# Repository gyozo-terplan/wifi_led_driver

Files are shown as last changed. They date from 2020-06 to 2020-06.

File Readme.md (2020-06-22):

# ESP8266 BASED WIFI LED DRIVER

ESP8266 based WiFi LED driver is a high capacity led driver, which can be operated via MQTT or with a physical button. It has 3-channels capable of delivering 1A current per channel. 

> **WARNING:**  **!!!  USE THIS DEVICE AT YOUR OWN RISK! I AM NOT AN EXPERT ON ELECTRONICS MALFUNCTIONS CAN HAPPEN WITH THE BOARD (fire hazard etc.) Always unplug it, if you do not use !!!**

# Features

- Controllable via WIFI + MQTT
- 3 channels, 1A current per channel
- Lights are dimmable
- Can be set up in a browser, no need to hard-code WiFi credentials
- Physical switch to turn the LED strips on and off
- MQTT Status feedback
- Openhab compatible
- Wired and OTA firmware update 

# Hardware

## Parts list

- 10K resistor
- ESP12
- LM2596SX-3.3/NOPB
- 560uF capacitor
- Inductor
- 680uF capacitor
- SS34-E3/57T schottky diode
- Header-Male-2.54_1x8
- Terminal Block 
- 100nF capacitor (optional)
- IRLB8743PBF transistor
- DC-005-5A-3.0 socket

Detailed parts list is in the pcb folder BOM file.

## Accessories needed

- Power suppply 12V 5A min. rated supply with 3.0 mm x 5.5 mm plug
- USB-TTL CP2102 (to upload firmware to the device) 
- Dupont cables (5 pieces)
- Momentary switch (optional)
- analog LED strip (3, 1A max)

## Assembly

- Order the PCB (gerber file in the pcb folder)
- Order parts 
- Solder the parts to the PCB. Beware the order of the soldering, if you are using soldering iron

The final device should look like this:
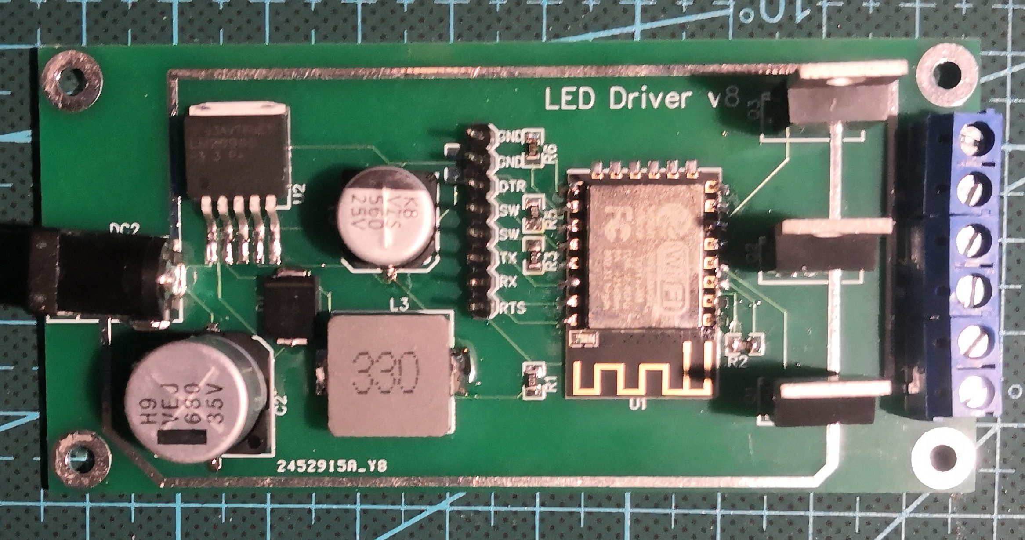
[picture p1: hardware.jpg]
Hardware


# Firmware

## Required software environment 

- Arduino IDE to flash the device before the first usage
- MQTT client to send commands to the unit via WiFi (it can be an app, or software running on a computer)
- MQTT broker on running on the same network as the LED driver  

## Firmware flash

- To upload the firmware you need to install Arduino IDE
- You need to install the ESP board in Arduino IDE (instructions [here](https://randomnerdtutorials.com/how-to-install-esp8266-board-arduino-ide/))
- Install IotWebConf and MQTT library for Arduino by Joel Gaehwiler (guide to install Arduino libraries [here](https://www.arduino.cc/en/guide/libraries))
- Open the firmware in Arduino IDE (located in the firmware folder: wifi_ledstrip.ino)
- Connect the CP2102 USB-TTL device to the computer via USB
- Connect the CP2102 USB-TTL device to the board, wiring diagram:

```
+----------------+               +----------------+
|                |               |                |
|             GND+---------------+GND             |
|                |               |                |
|              RX+---------------+TX  Wifi LED    |
|     CP2102     |               |     Driver     |
|              TX+---------------+RX              |
|                |               |                |
|             DTR+---------------+DTR             |
|                |               |                |
|             RTS+---------------+RTS             |
|                |               |                |
+----------------+               +----------------+
```

- Upload the firmware with Arduino IDE

# Setup

- The device will be in AP mode first when powered on, later it switches to client mode and try to connect to a hotspot 
- Search for a network on a WiFi capable device (smartphone, computer)
- Connect to the device (SSID: led_driver, password: proba1234)
- Go to the http://192.168.4.1  address in a browser
- Go to the configuration page
- You can set:
		- Thing name: device name
		- AP password: the password of the device if it is in AP mode
		- WiFi SSID: name of the WiFi hotspot where the device will connect if it switches to client mode
		- WiFi password: password of the WiFi hotspot where the device will connect if it switches to client mode
		- MQTT server address: address of the MQTT broker
		- MQTT topic name: the mqtt topic which will be used to send messages to the device
		- MQTT name: MQTT name of the device
		- Default light intensity: numeric value which sets the light intensity (between 0 and 100) if the button pressed on the device

## Usage

- Plug in the device, it should automatically connect to the WiFi network and to the MQTT broker
- Connect to the MQTT broker on your device (smartphone, tablet, computer, any device that can run MQTT device)
- Send the requested light intensity value to the ```
/MQTT topic name/MQTT name/action``` topic
- If the message received and the light intensity value is different than the previous you should get a message ```/MQTT topic name/MQTT name/status``` topic which shows you the light intensity which was just set
- If you would like to use the device without giving MQTT commands you can use a physical momentary switch, you can connect the switch to the SW pins

## TODO

- Improve thermal performance
- Create secure MQTT connection capability

## Copyright

See [LICENSE](https://github.com/gyozo-terplan/wifi_led_driver/blob/master/LICENSE) for details.

## Credits

- The firmware heavily based on Balázs Kelemen's [IotWebConf](https://github.com/prampec/IotWebConf) library

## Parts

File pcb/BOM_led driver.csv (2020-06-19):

ID | Name | Designator | Footprint | Quantity | Manufacturer Part | Manufacturer | Supplier | Supplier Part | LCSC Assembly
1 | 10K | R1,R2,R3,R5,R6 | 0805 | 5 | RC0805JR-0710KL | YAGEO | LCSC | C100047
2 | ESP12 | U1 | ESP-12F (ESP8266 MODULE) (BAGUNDA) | 1 | ESP-12F(ESP8266MOD) | Ai-Thinker | LCSC | C82891
3 | LM2596SX-3.3/NOPB | U2 | TO-263-5 | 1 | LM2596SX-3.3/NOPB | TI | LCSC | C7929 | Yes
4 | 560uF | C3 | CAP-T-10*10 | 1 | VZS561M1E1010-TRO | Lelon | LCSC | C249979
5 | Sunltech | L3 | L-SMD-13.45X12.6X6.5 | 1 | SLO1365H330MTT | Sunltech Tech | LCSC | C364090
6 | 680uF | C2 | CAP-T-12.5*13.5 | 1 | VEJ681M1V1313-TRO | Lelon | LCSC | C249685
7 | SS34-E3/57T | D1 | SMC(DO-214AB) | 1 | SS34-E3/57T | VISHAY | LCSC | C13354 | Yes
8 | Header-Male-2.54_1x8 | H2 | 210S-1X8P | 1 | 210S-1*8P L=11.6MMGold-plated black | Ckmtw | LCSC | C124381
9 | Terminal Block 2 | J1,J2,J3 | TERMINAL_BLOCK_2P_5 | 3 | ? |  | ME
10 | 100nF | C1 | 0805 | 1 | 0805F104Z500 | WTC | LCSC | C89574
11 | IRLB8743PBF | Q1,Q2,Q3 | TO-220(TO-220-3) | 3 | IRLB8743PBF | IR | LCSC | C2663
12 | DC-005-5A-3.0 | DC2 | DC-IN_3P-DC-005-5A-3.0 | 1 | DC-005-5A-3.0 | XKB Enterprise | LCSC | C388625

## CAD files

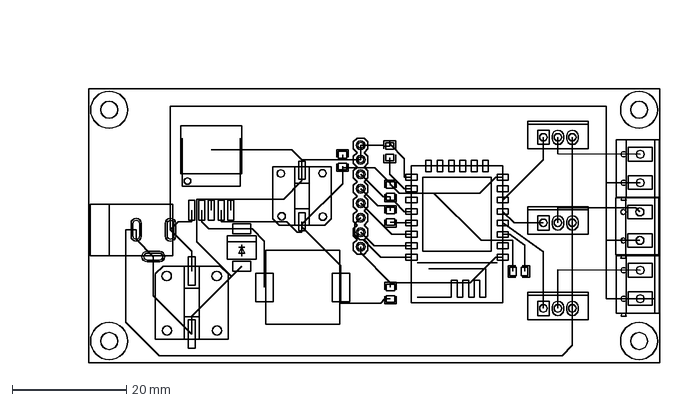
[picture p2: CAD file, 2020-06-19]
pcb/pcb.dxf
112.7 x 60.7 mm

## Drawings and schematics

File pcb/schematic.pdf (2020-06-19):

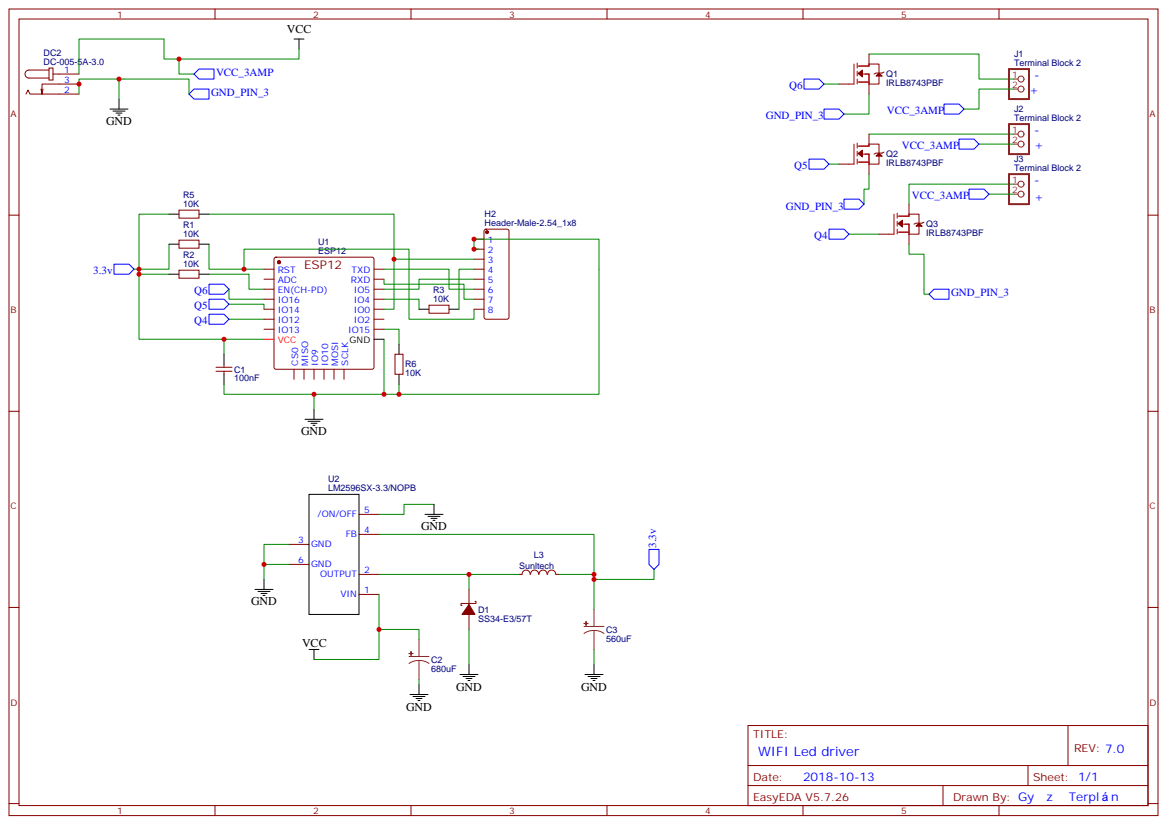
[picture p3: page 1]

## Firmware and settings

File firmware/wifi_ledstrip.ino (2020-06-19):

/// Loading libraries
#include <IotWebConf.h>
#include <MQTT.h>





/// Defining inputs and outputs of the ESP
#define J1_PIN 16   
#define J2_PIN 12 
#define J3_PIN 14  
#define BUTTON_READ 4 
#define BUTTON_SEND 5 


/// Defining GUI variables
#define STRING_LEN 128
#define NUMBER_LEN 32
const char thingName[] = "led_driver";
const char wifiInitialApPassword[] = "proba1234";
char mqttServerAddress[STRING_LEN];
char mqtt_topic[STRING_LEN];
char mqtt_name[STRING_LEN];
char default_intensity_input[STRING_LEN];


/// Defining variables of the button switch 
int intensity = 0;
int prev_intensity = 0;
long my_time = 0;
long debounce = 50; 
int multiplier;
int default_intensity;


/// Defining variables of the MQTT controll 
int state = HIGH;      
int reading;           
int previous = LOW; 



/// Callback method declarations
void wifiConnected();
void configSaved();
boolean formValidator();
void mqttMessageReceived(String &topic, String &payload);



/// Defining used modules
DNSServer dnsServer;
WebServer server(80);
WiFiClient net;
MQTTClient mqttClient;
HTTPUpdateServer httpUpdater;



/// GUI variable configuration
IotWebConf iotWebConf(thingName, &dnsServer, &server, wifiInitialApPassword);
IotWebConfParameter mqttServer_Param = IotWebConfParameter("MQTT server address", "mqttServer", mqttServerAddress, STRING_LEN);
IotWebConfParameter mqttTopic_Param = IotWebConfParameter("MQTT topic name", "mqtt_topic", mqtt_topic, STRING_LEN);
IotWebConfParameter mqttName_Param = IotWebConfParameter("MQTT name", "mqtt_name", mqtt_name, STRING_LEN);
IotWebConfParameter default_intensity_Param = IotWebConfParameter("Default light intensity", "default_intensity", default_intensity_input, NUMBER_LEN, "number", "1..100", NULL, "min='1' max='100' step='1'");


/// Defining variables for automatic reconnection
boolean needMqttConnect = false;
boolean needReset = false;
unsigned long lastMqttConnectionAttempt = 0;


/// Defining MQTT topics
char mqttActionTopic[STRING_LEN];
char mqttStatusTopic[STRING_LEN];





void setup() {
  
  Serial.begin(115200);
  Serial.println("Booting");


  /// Set the extra parameters of the GUI
  iotWebConf.addParameter(&mqttServer_Param);
  iotWebConf.addParameter(&mqttTopic_Param);
  iotWebConf.addParameter(&mqttName_Param);
  iotWebConf.addParameter(&default_intensity_Param);


  /// Set callback functions
  iotWebConf.setConfigSavedCallback(&configSaved);
  iotWebConf.setupUpdateServer(&httpUpdater);
  iotWebConf.setFormValidator(&formValidator);
  iotWebConf.setWifiConnectionCallback(&wifiConnected);


  /// Initialize the configuration
  boolean validConfig = iotWebConf.init();
  if (!validConfig)
  {
    mqttServerAddress[0] = '\0';
  }
  

  /// Set up required URL handlers on the web server
  server.on("/", handleRoot);
  server.on("/config", []{ iotWebConf.handleConfig(); });
  server.onNotFound([](){ iotWebConf.handleNotFound(); });

  
  /// Set up MQTT client
 
  mqttClient.begin(mqttServerAddress, net);
  mqttClient.onMessage(mqttMessageReceived);


  Serial.println("Ready");
  Serial.print("IP address: ");
  Serial.println(WiFi.localIP());


  /// Set ESP inputs and outputs 
  pinMode(J1_PIN, OUTPUT);
  pinMode(J2_PIN, OUTPUT);
  pinMode(J3_PIN, OUTPUT);
  pinMode(BUTTON_SEND, OUTPUT);
  pinMode(BUTTON_READ, INPUT_PULLUP);
  digitalWrite(BUTTON_SEND, LOW);

  /// Converting default intensity parameter from String to Int
  default_intensity = String(default_intensity_input).toInt();

}

 

void loop() {
 
  /// doLoop should be called as frequently as possible
  
  iotWebConf.doLoop();
  mqttClient.loop();
  
  
  /// Checking connections and subscribing to MQTT action topic
  if ((iotWebConf.getState() == IOTWEBCONF_STATE_ONLINE) && (!mqttClient.connected()))
  {
    Serial.println("MQTT reconnect");
    unsigned long now = millis();
  if (1000 > now - lastMqttConnectionAttempt)
  {
    // Do not repeat within 1 sec.
  }
  
  Serial.println("Connecting to MQTT server...");
  
  if (!mqttClient.connect(iotWebConf.getThingName())) {
    lastMqttConnectionAttempt = now;
    //  Serial.println(!mqttClient.connected());
  }
  Serial.println("Connected!");

  mqttClient.subscribe("/" + String(mqtt_topic) + "/" + mqtt_name + "/action");
  }


  if (needReset)
  {
    Serial.println("Rebooting after 1 second.");
    iotWebConf.delay(1000);
    ESP.restart();
  }


/// Set intensity in line with the multiplier to ensure switch will change the status of the driver   
 if (intensity>0) {
    multiplier=1;
   }
 
 else if (intensity==0) {
    multiplier=0;
    }


/// Read physical button value
  reading = digitalRead(BUTTON_READ);


/// Set the status of the LED strips if the button pressed
  if (reading != previous) {
    // reset the debouncing timer
        my_time = millis(); 
  }
 
  if ((millis() - my_time) > debounce) {

    if (reading != state) {
      
      state = reading;

      if (state == LOW) {
        multiplier = !multiplier;
      }

          intensity = multiplier*default_intensity;
    }
  }
     
/// Save the reading of the button for comparison
  previous = reading;

  
/// Write the outputs with the actual intensity value

  analogWrite(J1_PIN,   1024*float(intensity)/100 ); 
  analogWrite(J2_PIN,   1024*float(intensity)/100 );
  analogWrite(J3_PIN,   1024*float(intensity)/100 );
  
  
/// If Intensity value changed send an MQTT status message 
  
  if(prev_intensity!=intensity) {
  
  char outbound_msg[50];
  snprintf (outbound_msg, sizeof(outbound_msg), "%1d", intensity);

  mqttClient.publish("/" + String(mqtt_topic) + "/" + mqtt_name + "/status",  outbound_msg);
  }

/// Save the previous intensity value for comparison 
  prev_intensity=intensity;
 
}



void handleRoot()
{
  // -- Let IotWebConf test and handle captive portal requests.
  if (iotWebConf.handleCaptivePortal())
  {
    // -- Captive portal request were already served.
    return;
  }
  String s = "<!DOCTYPE html><html lang=\"en\"><head><meta name=\"viewport\" content=\"width=device-width, initial-scale=1, user-scalable=no\"/>";
  s += "<title>Led unit</title></head><body>Hello world!";
  s += "<ul>";
  s += "<li>MQTT server: ";
  s += mqttServerAddress;
  s += "</ul>";
  s += "<ul>";
  s += "<li>MQTT topic: ";
  s += mqtt_topic;
  s += "</ul>";
  s += "<ul>";
  s += "<li>MQTT device name: ";
  s += mqtt_name;
  s += "</ul>";
  s += "Go to <a href='config'>configure page</a> to change settings.";
  s += "</body></html>\n";

  server.send(200, "text/html", s);
}


void mqttMessageReceived(String &topic, String &payload)
{
  Serial.println("Incoming: " + topic + " - " + payload);

  
  if (topic.endsWith(String(mqtt_topic) + "/" + mqtt_name + "/action") )  
  {
   
	 intensity = payload.toInt();
  }
}



void configSaved()
{
  Serial.println("Configuration was updated.");
  needReset = true;
}


boolean formValidator()
{
  Serial.println("Validating form.");
  boolean valid = true;

  int l = server.arg(mqttServer_Param.getId()).length();
  if (l < 3)
  {
    mqttServer_Param.errorMessage = "Please provide at least 3 characters!";
    valid = false;
  }


  return valid;
}



void wifiConnected()
{
  needMqttConnect = true;
}
